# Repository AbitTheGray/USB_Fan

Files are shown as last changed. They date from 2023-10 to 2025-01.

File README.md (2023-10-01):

# USB Fan

Single-cell USB Fan with voltage selection and USB-C Charger built around `TP4056`+`DW01A` and `TPS61170`.

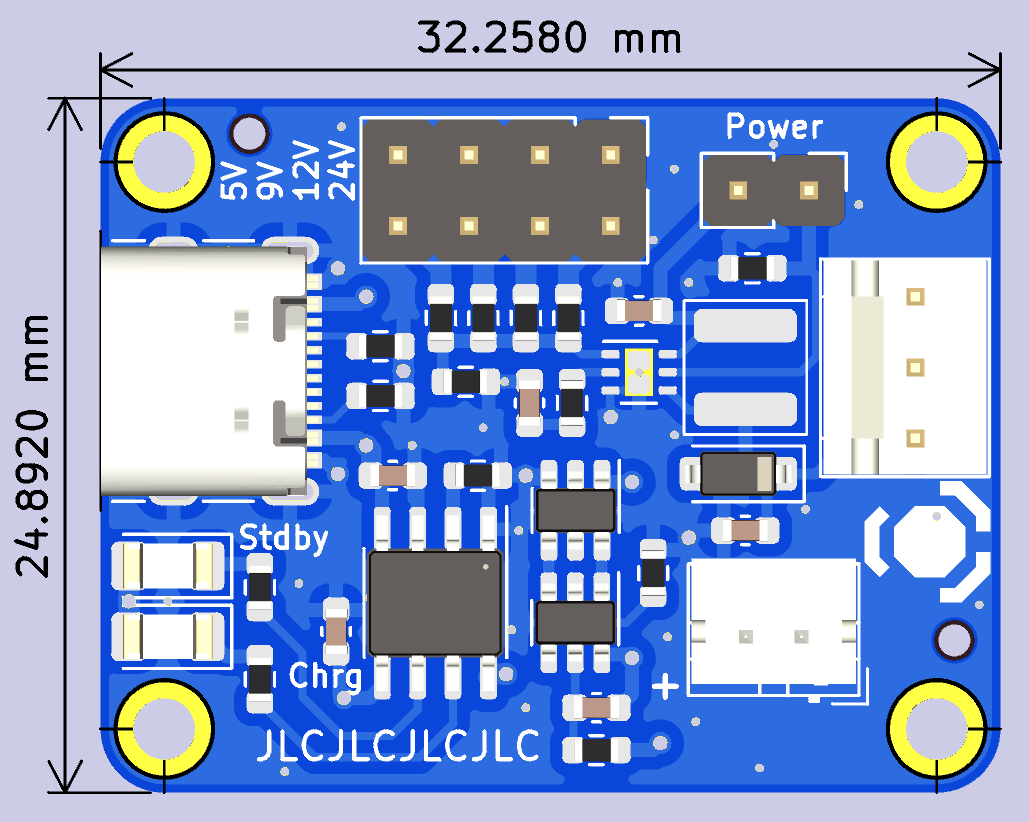
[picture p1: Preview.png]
PCB Preview


**This board is untested.**

Designed to be manufactured by [JLCPCB](https://jlcpcb.com/) as 4layer PCB.
*It is not possible to manufacture as 2layer PCB.*

## Features

- 4 fan voltages (5V / 9V / 12V / 24V)
  - Select **before** turning the SW1 on
- USB-C charging
  - 5V 1.5A max (5.1k resistors)
  - `TP4056` charger
    - Status LEDs
      - Red = Charging
      - Blue = Standby
    - 1S 1A charging (1 cell in series, unlimited in parallel)
  - 1.5A discharge (`DW01A`)
- Power-on switch
  - Only affects the output, battery can still charge
  - **Do not turn on when charging**
  - Minimum current runs through the switch
    - No special switch needed
    - It is not a toggle!

### Warnings

- There are no reverse-polarity protections
  - Not on battery or USB-C
- `D3`+`D4` don't have JLCPCB part number, pick any `1206` LEDs you like
- Default component placement has to be tweaked on JLCPCB online editor
  - `J1` shifted to right position
  - `L1` rotated 90deg
  - `U1`, `U2`, `U3` and `U4` must be rotated so 1st pin is in the corner with long line on Stencil layer
    - `U1` = top right, `U2` = top left, `U3` = bottom right, `U4` = top left

## TODO

- Power LED (white) ?
- Add assembly tooling holes

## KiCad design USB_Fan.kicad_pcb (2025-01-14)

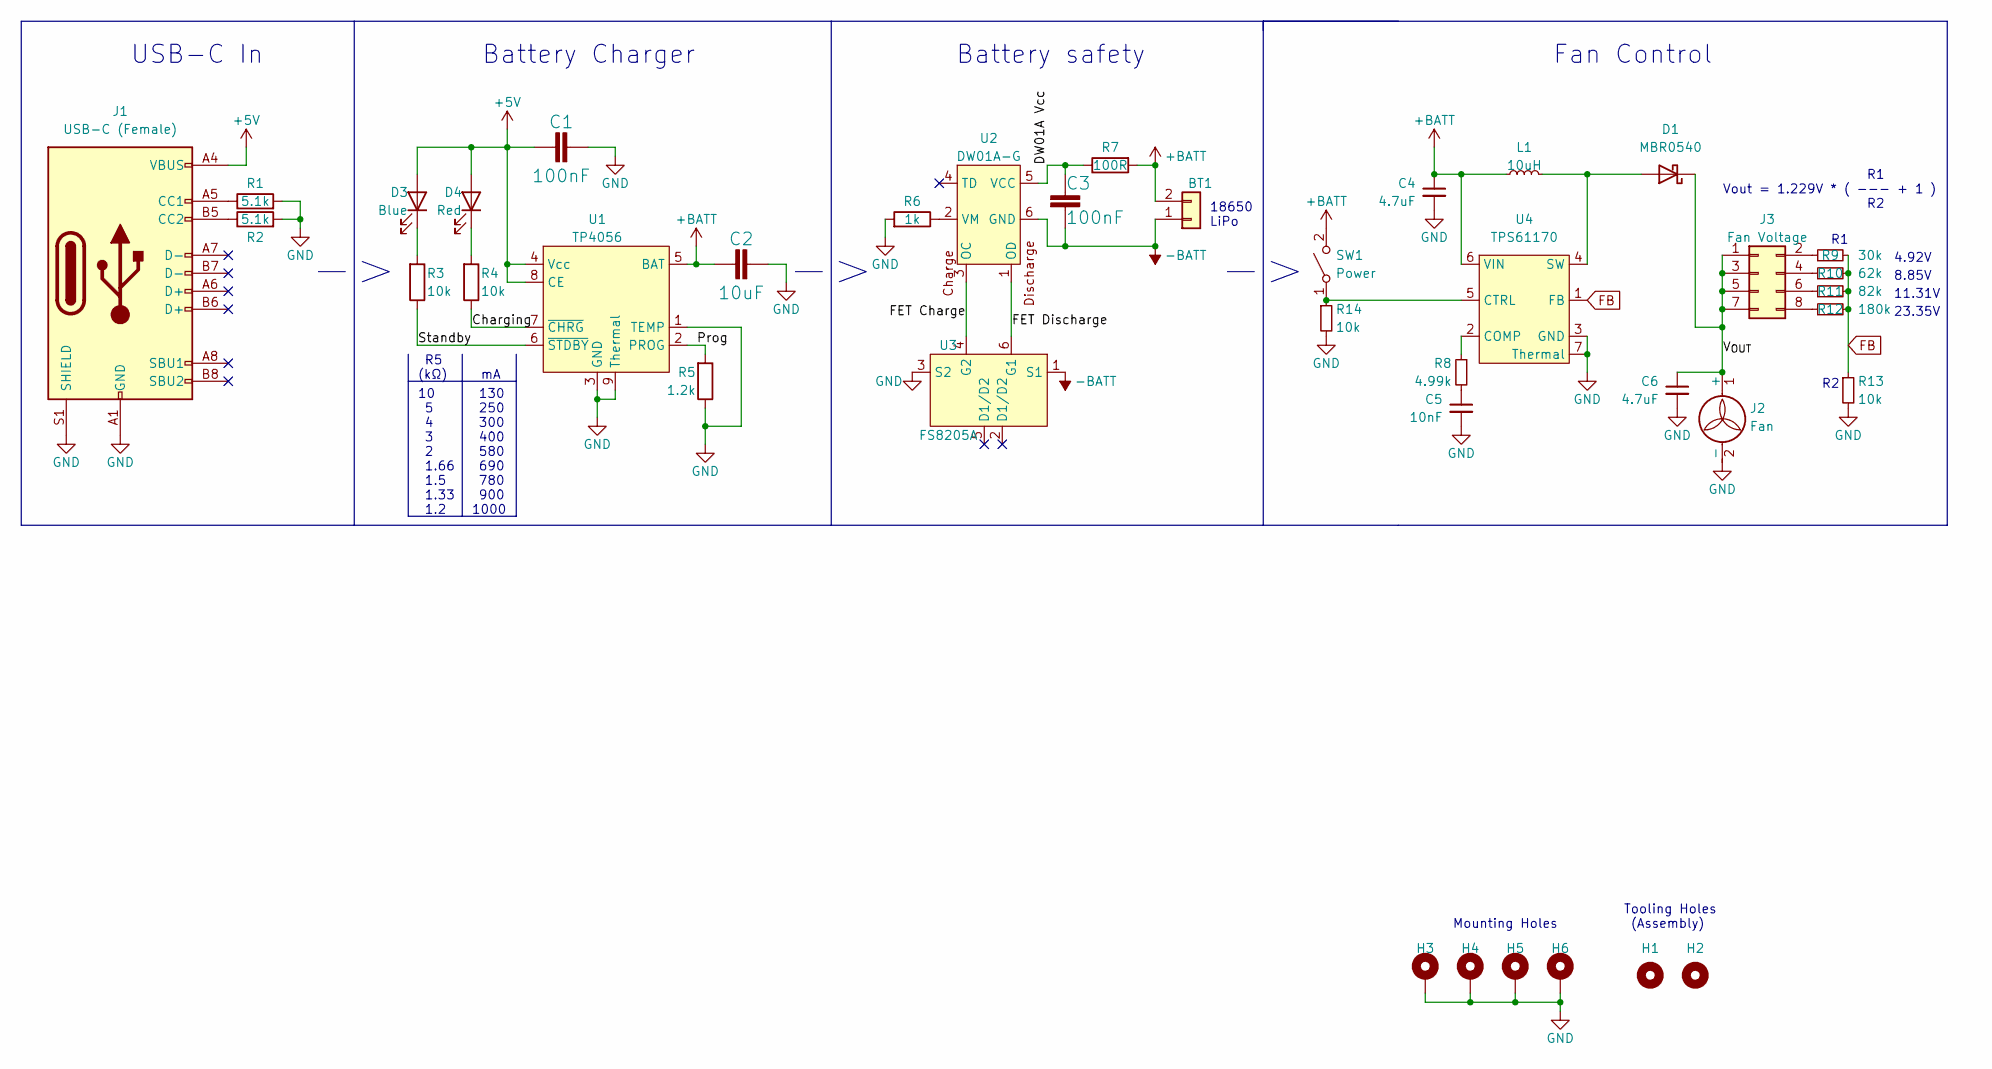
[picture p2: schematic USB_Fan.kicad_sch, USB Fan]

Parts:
BT1: Conn_01x02; JST_PH_B2B-PH-K_1x02_P2.00mm_Vertical; LCSC C18077744
C1, C3: 100nF; C_0603_1608Metric; LCSC C14663
C2: 10uF; C_0603_1608Metric; LCSC C96446
C4, C6: 4.7uF; C_0603_1608Metric; LCSC C19666
C5: 10nF; C_0603_1608Metric; LCSC C57112
D1: MBR0540; D_SOD-123; LCSC C116159
D3: Blue; LED_1206_3216Metric; LCSC C965827
D4: Red; LED_1206_3216Metric; LCSC C2827254
H1, H2: MountingHole_Pad; JLCPCB ToolingHole
H3, H4, H5, H6: MountingHole_Pad; MountingHole_2.2mm_M2_ISO7380_Pad
J1: USB-C (Female); USB_C_Receptacle_GCT_USB4105-xx-A_16P_TopMnt_Horizontal; LCSC C2765186
J2: Fan; FanPinHeader_1x03_P2.54mm_Vertical; LCSC C234181
J3: Fan Voltage; PinHeader_2x04_P2.54mm_Vertical
L1: 10uH; Inductor 4x4; LCSC C497803
R1, R2: 5.1k; R_0603_1608Metric; LCSC C23186
R3, R4, R13, R14: 10k; R_0603_1608Metric; LCSC C25804
R5: 1.2k; R_0603_1608Metric; LCSC C22765
R6: 1k; R_0603_1608Metric; LCSC C21190
R7: 100R; R_0603_1608Metric; LCSC C22775
R8: 4.99k; R_0603_1608Metric; LCSC C2988946
R9: 30k; R_0603_1608Metric; LCSC C22984
R10: 62k; R_0603_1608Metric; LCSC C23221
R11: 82k; R_0603_1608Metric; LCSC C23254
R12: 180k; R_0603_1608Metric; LCSC C22827
SW1: Power; PinHeader_1x02_P2.54mm_Vertical
U1: TP4056; HSOP-8-1EP_3.9x4.9mm_P1.27mm_EP2.41x3.1mm_ThermalVias; LCSC C16581
U2: DW01A-G; SOT-23-6; LCSC C351410
U3: FS8205A; SOT-23-6; LCSC C908265
U4: TPS61170; DFN-6-1EP_2x2mm_P0.65mm_EP1.01x1.7mm; LCSC C15163

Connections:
+5V: C1.1, D3.2 (A), D4.2 (A), J1.A4 (VBUS), J1.A9 (VBUS), J1.B4 (VBUS), J1.B9 (VBUS), U1.4 (Vcc), U1.8 (CE)
+BATT: BT1.2, C2.1, C4.1, L1.1, R7.2, SW1.2 (B), U1.5 (BAT), U4.6 (VIN)
-BATT: BT1.1, C3.2, U2.6 (GND), U3.1 (S1)
/Charging: R4.1, U1.7 (~CHRG)
/DW01A Vcc: C3.1, R7.1, U2.5 (VCC)
/FET Charge: U2.3 (OC), U3.4 (G2)
/FET Discharge: U2.1 (OD), U3.6 (G1)
/Prog: R5.2, U1.2 (PROG)
/Standby: R3.1, U1.6 (~STDBY)
/V_{OUT}: C6.1, D1.1 (K), J2.1 (+), J3.1, J3.3, J3.5, J3.7
FB: R9.2, R10.2, R11.2, R12.2, R13.1, U4.1 (FB)
GND: C1.2, C2.2, C4.2, C5.2, C6.2, H3.1, H4.1, H5.1, H6.1, J1.A1 (GND), J1.A12 (GND), J1.B1 (GND), J1.B12 (GND), J1.S1 (SHIELD), J2.2 (-), R1.2, R2.2, R5.1, R6.2, R13.2, R14.2, U1.1 (TEMP), U1.3 (GND), U1.9 (Thermal), U3.3 (S2), U4.3 (GND), U4.7 (Thermal)
unnamed: C5.1, R8.2
unnamed: D1.2 (A), L1.2, U4.4 (SW)
unnamed: D3.1 (K), R3.2
unnamed: D4.1 (K), R4.2
unnamed: J1.A5 (CC1), R1.1
unnamed: J1.B5 (CC2), R2.1
unnamed: J3.2, R9.1
unnamed: J3.4, R10.1
unnamed: J3.6, R11.1
unnamed: J3.8, R12.1
unnamed: R14.1, SW1.1 (A), U4.5 (CTRL)
unnamed: R6.1, U2.2 (VM)
unnamed: R8.1, U4.2 (COMP)

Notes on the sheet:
8.85V
130 250 300 400 580 690 780 900 1000
18650 LiPo
USB-C In
R5 (kΩ)
Tooling Holes (Assembly)
Fan Control
10 5 4 3 2 1.66 1.5 1.33 1.2
Battery Charger
R1 Vout = 1.229V * ( --- + 1 ) R2
Battery safety
11.31V
Mounting Holes
4.92V
23.35V

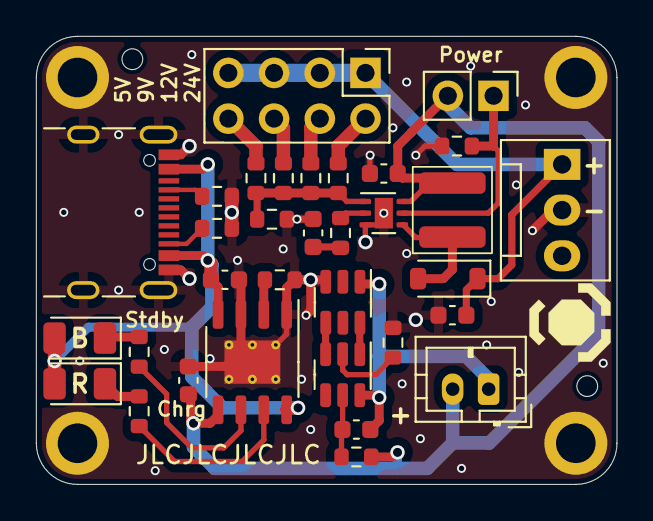
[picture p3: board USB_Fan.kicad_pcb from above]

Board: 4 copper layers, 32.3 x 24.9 mm, 39 parts (0 on the bottom side), 25 nets.

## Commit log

2023-09-21 Initial version
    [USB_Fan.kicad_pcb, USB_Fan.kicad_sch]
2023-09-29 Fix problems on the PCB
    [USB_Fan.kicad_pcb, USB_Fan.kicad_sch]
2023-10-01 Add tooling holes
    [USB_Fan.kicad_pcb, USB_Fan.kicad_sch]
2023-10-01 Minor tweaks to the PCB
    [USB_Fan.kicad_pcb]
2024-03-16 KiCad 8
    [USB_Fan.kicad_pcb, USB_Fan.kicad_sch]
2024-06-13 Revision 2
    [USB_Fan.kicad_pcb, USB_Fan.kicad_sch]
2025-01-14 Minor tweak for manufacturing
    [USB_Fan.kicad_pcb, USB_Fan.kicad_sch]
